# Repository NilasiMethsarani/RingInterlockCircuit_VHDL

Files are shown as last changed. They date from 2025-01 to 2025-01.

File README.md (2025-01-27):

Ring Interlock Circuit for EV Charging

This repository contains the design and implementation of a Ring Interlock Circuit for electric vehicle (EV) charging, using a CPLD (Complex Programmable Logic Device), specifically the EPM240T100C5N. The interlock circuit enhances the safety, efficiency, and reliability of EV charging systems by ensuring dynamic power sharing and robust fault prevention mechanisms.
Key Features

    Dynamic Power Sharing: Efficient distribution of power between multiple EVs to optimize charging performance.
    Enhanced Prioritization: Ensures prioritized power delivery based on load requirements.
    Short Circuit Prevention: Detects and prevents potential short circuits during charging.
    Compact and Scalable Design: Designed for scalability, leveraging the EPM240T100C5N CPLD for cost-effective implementation.

Design Components

    Technology Used:
        CPLD Model: EPM240T100C5N
        Quartus Prime for synthesis and implementation.
        ModelSim for simulation.
        Proteus for circuit-level design and testing.

    Input Signals:
        EV charging status.
        Fault detection inputs.
        Load conditions for power prioritization.

    Output Signals:
        Control signals to charging ports.
        Fault notifications.
        Power allocation indicators.

Objectives

    Ensure safe and efficient charging of multiple EVs using an interlock mechanism.
    Provide a cost-effective solution with minimal hardware overhead.
    Test and validate the design against real-world fault conditions.

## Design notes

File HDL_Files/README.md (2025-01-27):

# Interlock Combined Module

This Verilog module `InterlockCombined` combines multiple instances of `Interlock` modules to create a comprehensive interlocking mechanism for controlling various contacts or devices. 

## Description

The `InterlockCombined` module integrates eight individual `Interlock` modules, each responsible for managing the interlocking logic for a specific set of contacts or devices. These modules are named `InterlockA` through `InterlockH`.

## Inputs

- **i_AA to i_HH**: Feedback inputs representing the current state of each contactor or device.
  
## Outputs

- **o_A to o_H**: Outputs controlling the activation of each contactor or device based on the interlocking logic.

## Interlocking Logic

The interlocking logic for each contactor or device is implemented within their respective `Interlock` modules. These modules utilize the feedback inputs to determine whether a particular contactor or device can be activated based on predefined interlocking conditions.

## Usage

To use the `InterlockCombined` module in your Verilog design, instantiate it in your top-level module and connect the required inputs and outputs as shown in the example provided.

```verilog
module YourTopModule (
    // Define your inputs and outputs here
    ...
);

    // Instantiate InterlockCombined module
    InterlockCombined Interlock (
        .i_AA(input_signal_AA),
        .i_BA(input_signal_BA),
        // Connect other input signals
        .o_A(output_signal_A),
        .o_B(output_signal_B),
        // Connect other output signals
    );

    // Other module instantiations and logic
    ...

endmodule

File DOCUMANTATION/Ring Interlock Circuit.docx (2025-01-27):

Ring Interlock Circuit

Introduction

In the pursuit of safe and efficient electric vehicle (EV) charging infrastructure, the evolution from sequential circuits to ring interlock circuits marks a significant advancement. The transition is driven by the imperative to enhance power sharing capabilities while mitigating potential risks, such as short circuits that could lead to hazardous situations including fires.

Previously, sequential circuits comprised four modules with two ports each, facilitating the connection of vehicles to the charging system. However, inherent limitations in sequential configurations necessitated a paradigm shift towards ring interlock circuits, wherein the safety and efficiency of EV charging systems are significantly augmented.

The fundamental principle guiding the development of ring interlock circuits is twofold: power sharing and prioritization. In essence, the system orchestrates the allocation of power among connected vehicles dynamically, ensuring equitable charging while accommodating varying demands. This innovation enables seamless integration of multiple vehicles into the charging infrastructure, fostering scalability and adaptability to evolving needs.

Central to the design philosophy of ring interlock circuits is the preservation of safety. Unlike sequential circuits, where the risk of short circuits between vehicles posed a formidable challenge, ring interlock configurations mitigate this risk by enforcing a strict prohibition on short paths between vehicles. This crucial safeguard ensures that the charging process proceeds without compromising safety or jeopardizing the integrity of the system.

Moreover, the modular nature of ring interlock circuits empowers operators to customize charging priorities based on user preferences and operational requirements. By allocating higher priority to specific vehicles, such as those in urgent need of charging, while maintaining equitable access for all users, the system optimizes resource utilization and enhances user satisfaction.

Comparison between Previous Sequential Circuit and Ring Interlock Circuit:

Previous Sequential Circuit:

1. Topology: The previous sequential circuit comprised a linear topology, with four modules arranged sequentially. Each module featured two ports for connecting vehicles.

2. Operation: Vehicles were connected to the ports of the modules sequentially, resulting in a linear flow of power through the system. Charging prioritization was limited, typically following a first-come, first-served basis.

3. Constraints: One of the primary constraints of the sequential circuit was the potential for short paths between vehicles, leading to safety hazards such as short circuits and fire risks.

4. Logic Development: The logic governing the operation of the sequential circuit was relatively straightforward, primarily focusing on managing the sequential flow of power to connected vehicles. Safety protocols were limited to basic measures to prevent short circuits.

F

E

D

C

B

A

Here A, B, C, D, E and F represent the feedbacks of modules

(contactors) & A^(-1) , B^(-1) , C^(-1) , D^(-1) , E^(-1) and F^(-1) represent the current input status.

A→(ABCDEFA^(-1) )^(-1)

B→(ABCDEFB^(-1) )^(-1)

C→(ABCDEFC^(-1) )^(-1)

D→(ABCDEFD^(-1) )^(-1)

E→(ABCDEFE^(-1) )^(-1)

F→(ABCDEFF^(-1) )^(-1)

Ring Interlock Circuit:

1. Topology: The ring interlock circuit features a circular or ring-shaped topology, with four modules interconnected in a closed loop. Each module retains four ports for vehicle connection.

2. Operation: In contrast to the linear flow of power in the sequential circuit, the ring interlock circuit enables dynamic power sharing among connected vehicles. Charging prioritization is enhanced, allowing for the allocation of higher priority to specific vehicles based on user requirements.

3. Constraints: The ring interlock circuit addresses the safety concerns of the previous sequential circuit by enforcing strict prohibition on short paths between vehicles. This significantly reduces the risk of short circuits and associated safety hazards.

4. Logic Development: The logic development for the ring interlock circuit is more intricate compared to the previous sequential circuit. It involves algorithms and protocols for dynamic power allocation, prioritization of charging, and stringent safety measures to prevent short paths between vehicles.

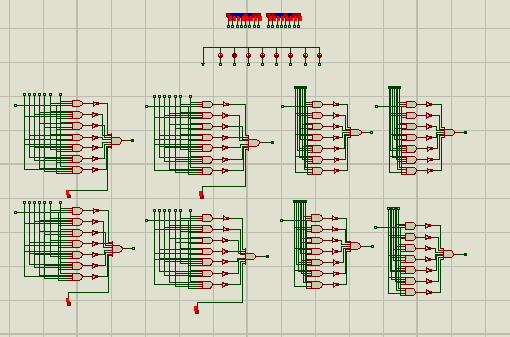
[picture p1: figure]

-Contactors

- Ports

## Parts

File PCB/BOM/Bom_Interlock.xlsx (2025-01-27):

Part | Qty | Manufacturer | Manufacturer Part Number | DigiKey Part Number | LCSC Part Number | Description | Link
J1, J2 | 2 | TE Connectivity AMP Connectors | 1-2314812-6 | 17-1-2314812-6-ND |  | 16P,2MM,B-B,REC,DRVT,2.0,0.1AU,T | Link (https://www.digikey.com/en/products/detail/te-connectivity-amp-connectors/1-2314812-6/11502796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)
J3 | 1 | Würth Elektronik | 61301021821 | 732-2861-ND |  | CONN HDR 10POS 0.1 GOLD PCB | Link (https://www.digikey.com/en/products/detail/w%C3%BCrth-elektronik/61301021821/2508630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)
R1, R2, R3, R4, R5, R6, R7, R8, R14 | 9 | Stackpole Electronics Inc | RMCF0603JT220R | RMCF0603JT220RTR-ND |  | RES 220 OHM 5% 1/10W 0603 | Link (https://www.digikey.com/en/products/detail/stackpole-electronics-inc/RMCF0603JT220R/1758014)
R9, R10, R11, R12, R13 | 5 | Bourns Inc. | CRT0603-BY-1002EAS | CRT0603-BY-1002EASTR-ND |  | RES SMD 10K OHM 1/10W 0.1% 0603 | Link (https://www.digikey.com/en/products/detail/bourns-inc/CRT0603-BY-1002EAS/5992173)
C1, C2, C3, C4, C5, C6, C7, C8, C9 | 9 | Murata Electronics | GRM188R71C104MA01D | 490-11510-2-ND |  | CAP CER 0.1UF 16V X7R 0603 | Link (https://www.digikey.com/en/products/detail/murata-electronics/GRM188R71C104MA01D/4420803)
C10 | 1 | Murata Electronics | GRM188R61C106MAALD | 490-10729-2-ND |  | CAP CER 10UF 16V X5R 0603 | Link (https://www.digikey.com/en/products/detail/murata-electronics/GRM188R61C106MAALD/5251371)
C11 | 1 | KEMET | C0603C104K4RAC3077 | 399-C0603C104K4RAC3077TR-ND |  | .100UF 16.0V | Link (https://www.digikey.com/en/products/detail/kemet/C0603C104K4RAC3077/22058627)
D1, D2, D3, D4, D5, D6, D7, D8, D9 | 9 | Broadcom Limited | HSMS-C190 | 516-1422-2-ND |  | LED RED DIFFUSED SMD | Link (https://www.digikey.com/en/products/detail/broadcom-limited/HSMS-C190/637683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)
Y1 | 1 | CTS-Frequency Controls | CB3LV-3C-50M000000 | 110-CB3LV-3C-50M000000TR-ND |  | XTAL OSC XO 50.0000MHZ HCMOS TTL | Link (https://www.digikey.com/en/products/detail/cts-frequency-controls/CB3LV-3C-50M000000/280321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)
U1 | 1 | Intel | EPM240T100C5N | 544-1964-ND | C10041 | IC CPLD 192MC 4.7NS 100TQFP | Link (https://www.lcsc.com/product-detail/Programmable-Logic-Device-CPLDs-FPGAs_Intel-Altera-EPM240T100C5N_C10041.html)
U2 | 1 | Texas Instruments | TLV1117-33IDCYRG3 | 296-50543-2-ND |  | IC REG LIN 3.3V 800MA SOT223-4 | Link (https://www.digikey.com/en/products/detail/texas-instruments/TLV1117-33IDCYRG3/1677132)

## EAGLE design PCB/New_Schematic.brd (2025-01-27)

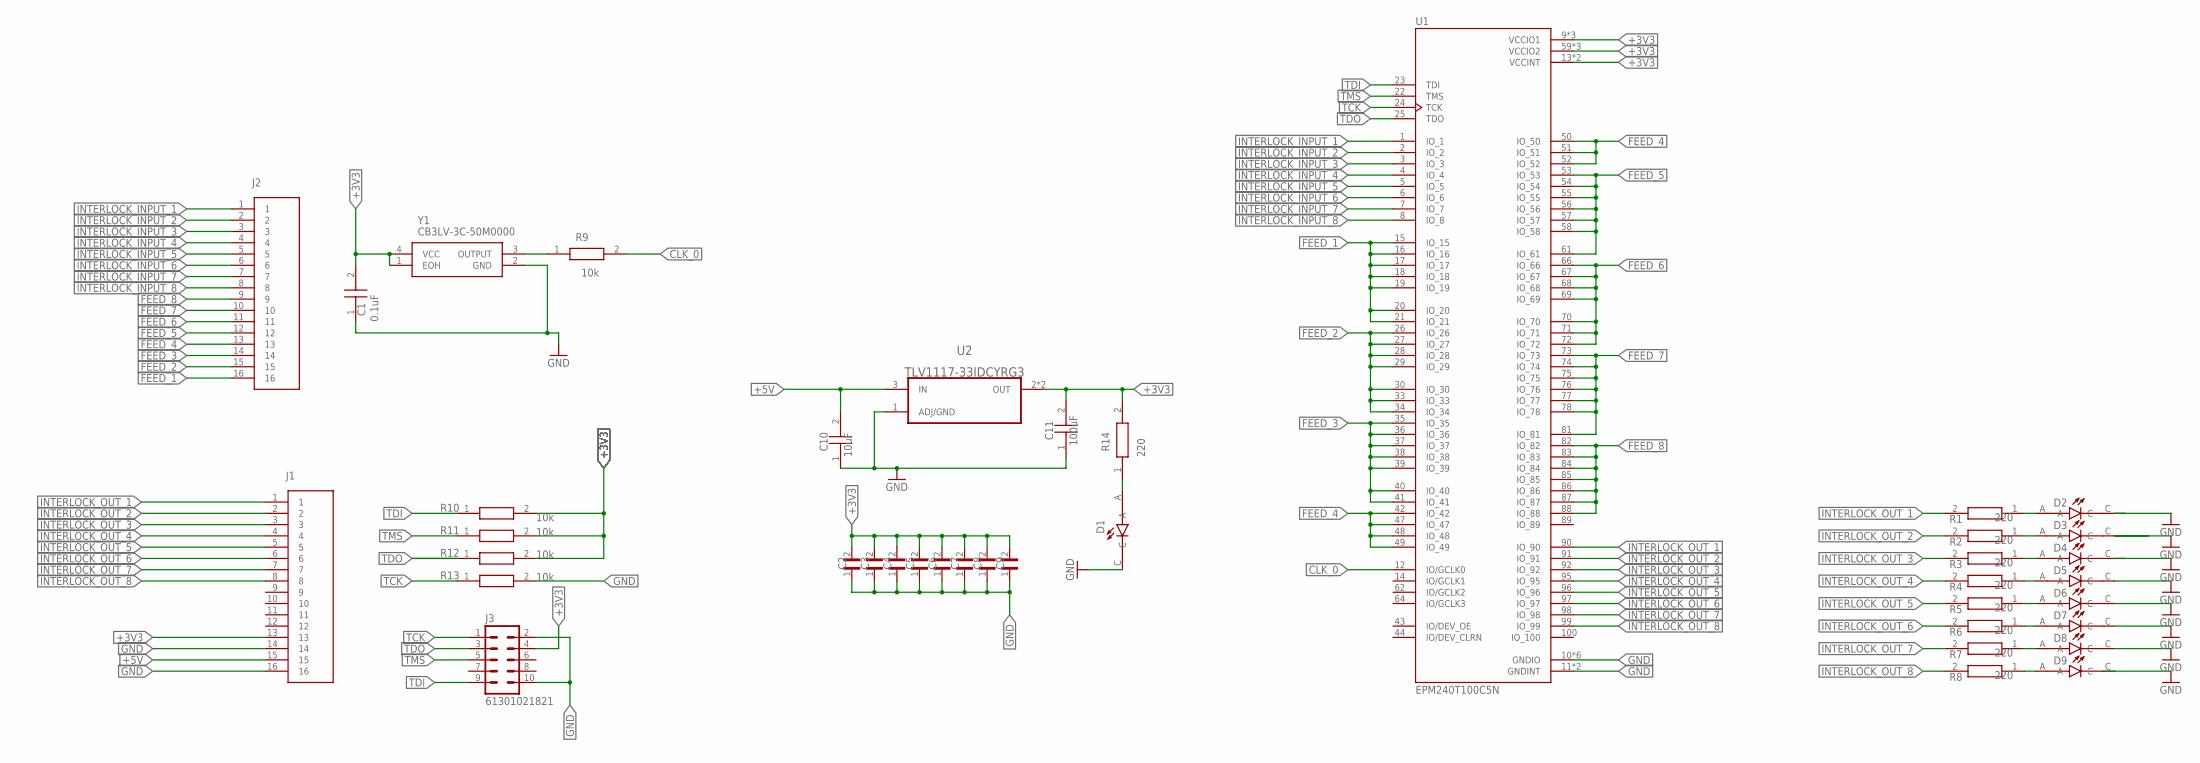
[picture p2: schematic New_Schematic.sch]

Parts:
C1: GRM188R71C104MA01D; CAPC1608X90N
C2, C3, C4, C5, C6, C7, C8, C9: GRM155R70J104KA01D; CAPC1005X55N
C10, C11: 0603X106M160CT; CAPC1608X95N
D1, D2, D3, D4, D5, D6, D7, D8, D9: HSMS-C190; LEDM1608X80
J1, J2: 1-2314812-6; TE_1-2314812-6
J3: 61301021821; 2X05-PIN
R1, R2, R3, R4, R5, R6, R7, R8, R14: MCT06030D2200BP100; RESC1608X55N
R9, R10, R11, R12, R13: CRT0603-BY-1002EAS; RESC1608X60N
U1: EPM240T100C5N; QFP50P1600X1600X120-100N
U2: TLV1117-33IDCYRG3; SOT230P700X180-4N
Y1: CB3LV-3C-50M0000; CB3LV3C50M0000

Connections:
+3V3: C1.2, C2.2, C3.2, C4.2, C5.2, C6.2, C7.2, C8.2, C9.2, C11.2, J1.13, J3.4, R10.2, R11.2, R12.2, R14.2, U1.9 (VCCIO1), U1.13 (VCCINT), U1.31 (VCCIO1), U1.45 (VCCIO1), U1.59 (VCCIO2), U1.63 (VCCINT), U1.80 (VCCIO2), U1.94 (VCCIO2), U2.2 (OUT), U2.4 (OUT), Y1.1 (EOH), Y1.4 (VCC)
+5V: C10.2, J1.15, U2.3 (IN)
CLK_0: R9.2, U1.12 (IO/GCLK0)
FEED_1: J2.16, U1.15 (IO_15), U1.16 (IO_16), U1.17 (IO_17), U1.18 (IO_18), U1.19 (IO_19), U1.20 (IO_20), U1.21 (IO_21)
FEED_2: J2.15, U1.26 (IO_26), U1.27 (IO_27), U1.28 (IO_28), U1.29 (IO_29), U1.30 (IO_30), U1.33 (IO_33), U1.34 (IO_34)
FEED_3: J2.14, U1.35 (IO_35), U1.36 (IO_36), U1.37 (IO_37), U1.38 (IO_38), U1.39 (IO_39), U1.40 (IO_40), U1.41 (IO_41)
FEED_4: J2.13, U1.42 (IO_42), U1.47 (IO_47), U1.48 (IO_48), U1.49 (IO_49), U1.50 (IO_50), U1.51 (IO_51), U1.52 (IO_52)
FEED_5: J2.12, U1.53 (IO_53), U1.54 (IO_54), U1.55 (IO_55), U1.56 (IO_56), U1.57 (IO_57), U1.58 (IO_58), U1.61 (IO_61)
FEED_6: J2.11, U1.66 (IO_66), U1.67 (IO_67), U1.68 (IO_68), U1.69 (IO_69), U1.70 (IO_70), U1.71 (IO_71), U1.72 (IO_72)
FEED_7: J2.10, U1.73 (IO_73), U1.74 (IO_74), U1.75 (IO_75), U1.76 (IO_76), U1.77 (IO_77), U1.78 (IO_78), U1.81 (IO_81)
FEED_8: J2.9, U1.82 (IO_82), U1.83 (IO_83), U1.84 (IO_84), U1.85 (IO_85), U1.86 (IO_86), U1.87 (IO_87), U1.88 (IO_88)
GND: C1.1, C2.1, C3.1, C4.1, C5.1, C6.1, C7.1, C8.1, C9.1, C10.1, C11.1, D1.C, D2.C, D3.C, D4.C, D5.C, D6.C, D7.C, D8.C, D9.C, J1.14, J1.16, J3.2, J3.10, R13.2, U1.10 (GNDIO), U1.11 (GNDINT), U1.32 (GNDIO), U1.46 (GNDIO), U1.60 (GNDIO), U1.65 (GNDINT), U1.79 (GNDIO), U1.93 (GNDIO), U2.1 (ADJ/GND), Y1.2 (GND)
INTERLOCK_INPUT_1: J2.1, U1.1 (IO_1)
INTERLOCK_INPUT_2: J2.2, U1.2 (IO_2)
INTERLOCK_INPUT_3: J2.3, U1.3 (IO_3)
INTERLOCK_INPUT_4: J2.4, U1.4 (IO_4)
INTERLOCK_INPUT_5: J2.5, U1.5 (IO_5)
INTERLOCK_INPUT_6: J2.6, U1.6 (IO_6)
INTERLOCK_INPUT_7: J2.7, U1.7 (IO_7)
INTERLOCK_INPUT_8: J2.8, U1.8 (IO_8)
INTERLOCK_OUT_1: J1.1, R1.2, U1.90 (IO_90)
INTERLOCK_OUT_2: J1.2, R2.2, U1.91 (IO_91)
INTERLOCK_OUT_3: J1.3, R3.2, U1.92 (IO_92)
INTERLOCK_OUT_4: J1.4, R4.2, U1.95 (IO_95)
INTERLOCK_OUT_5: J1.5, R5.2, U1.96 (IO_96)
INTERLOCK_OUT_6: J1.6, R6.2, U1.97 (IO_97)
INTERLOCK_OUT_7: J1.7, R7.2, U1.98 (IO_98)
INTERLOCK_OUT_8: J1.8, R8.2, U1.99 (IO_99)
unnamed: D2.A, R1.1
unnamed: D3.A, R2.1
unnamed: D4.A, R3.1
unnamed: D5.A, R4.1
unnamed: D6.A, R5.1
unnamed: D7.A, R6.1
unnamed: D8.A, R7.1
unnamed: D9.A, R8.1
unnamed: R9.1, Y1.3 (OUTPUT)
unnamed: D1.A, R14.1
TCK: J3.1, R13.1, U1.24 (TCK)
TDI: J3.9, R10.1, U1.23 (TDI)
TDO: J3.3, R12.1, U1.25 (TDO)
TMS: J3.5, R11.1, U1.22 (TMS)

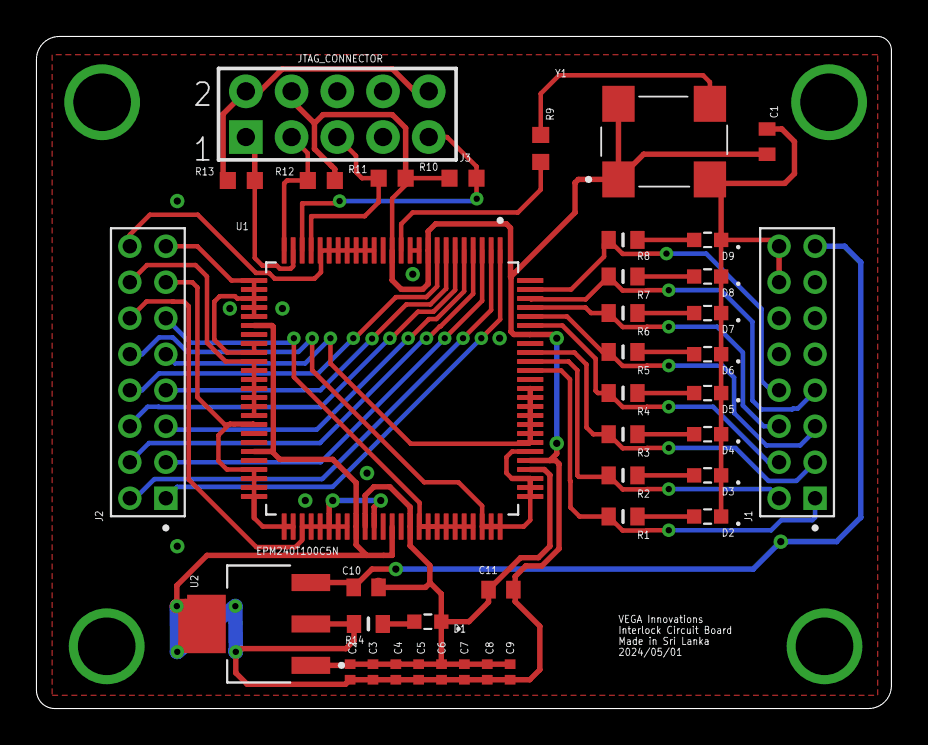
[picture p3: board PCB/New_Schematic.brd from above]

Board: 2 copper layers, 47.5 x 37.3 mm, 40 parts (0 on the bottom side), 42 nets.

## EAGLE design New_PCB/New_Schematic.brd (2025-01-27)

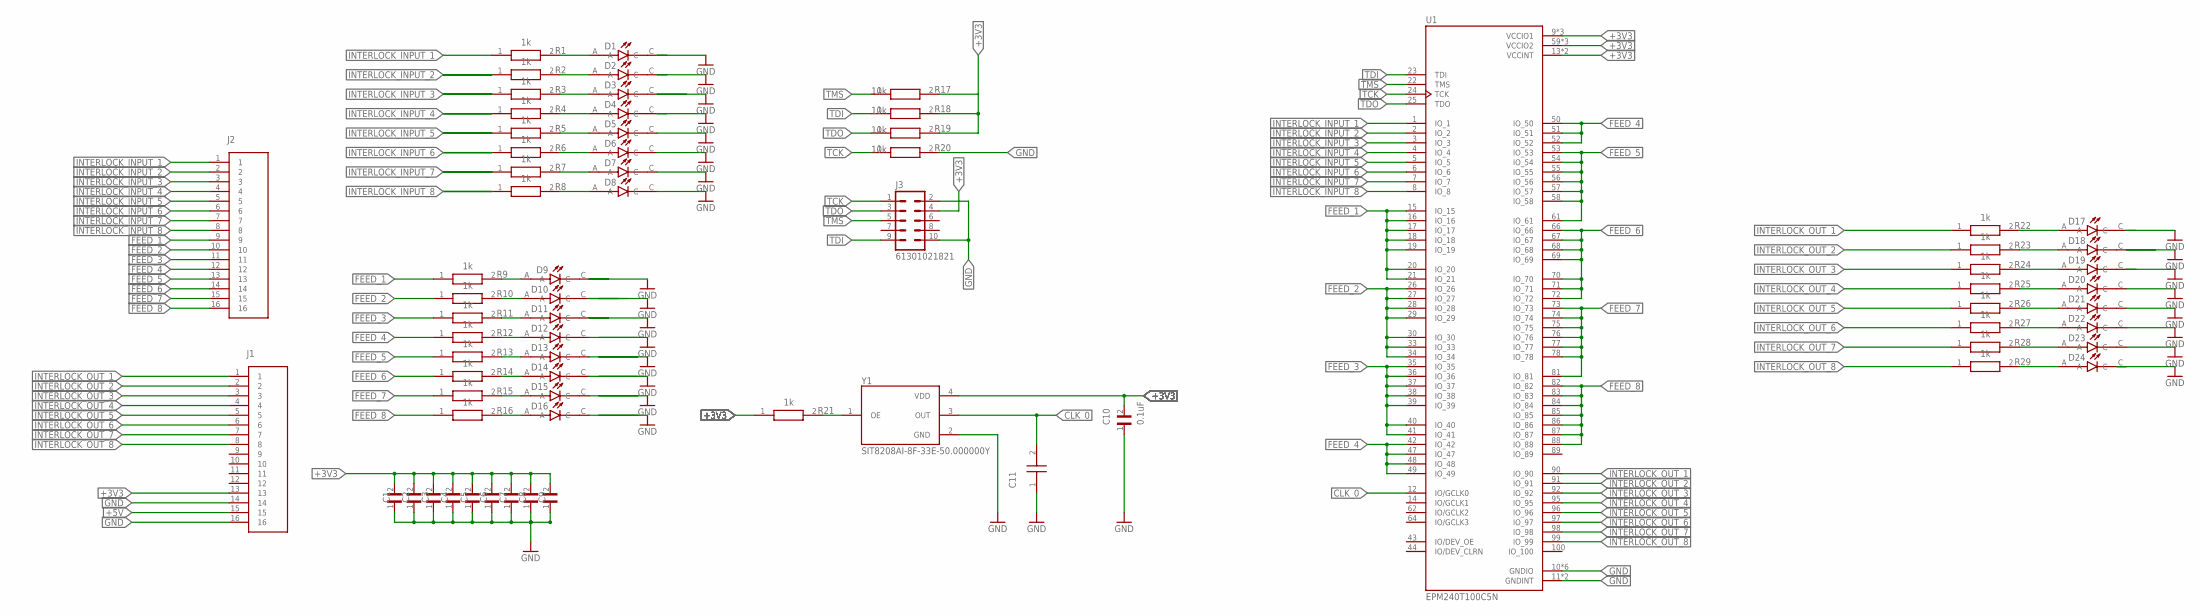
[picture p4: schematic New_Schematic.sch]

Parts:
C1, C2, C3, C4, C5, C6, C7, C8, C9, C10: GRM155R70J104KA01D; CAPC1005X55N
C11: GRM1883U2A150JZ01B; CAPC1608X90N
D1, D2, D3, D4, D5, D6, D7, D8, D9, D10, D11, D12, D13, D14, D15, D16, D17, D18, D19, D20, D21, D22, D23, D24: HSMS-C190; LEDM1608X80
J1, J2: 1-2314812-6; TE_1-2314812-6
J3: 61301021821; 2X05-PIN
R1, R2, R3, R4, R5, R6, R7, R8, R9, R10, R11, R12, R13, R14, R15, R16, R21, R22, R23, R24, R25, R26, R27, R28, R29: ERJS03D1001V; RESC1608X55N
R17, R18, R19, R20: CRT0603-BY-1002EAS; RESC1608X60N
U1: EPM240T100C5N; QFP50P1600X1600X120-100N
Y1: SIT8208AI-8F-33E-50.000000Y; OSC_SIT8208AI-8F-33E-50.000000Y

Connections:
+3V3: C1.2, C2.2, C3.2, C4.2, C5.2, C6.2, C7.2, C8.2, C9.2, C10.2, J1.13, J3.4, R17.2, R18.2, R19.2, R21.1, U1.9 (VCCIO1), U1.13 (VCCINT), U1.31 (VCCIO1), U1.45 (VCCIO1), U1.59 (VCCIO2), U1.63 (VCCINT), U1.80 (VCCIO2), U1.94 (VCCIO2), Y1.4 (VDD)
+5V: J1.15
CLK_0: C11.2, U1.12 (IO/GCLK0), Y1.3 (OUT)
FEED_1: J2.9, R9.1, U1.15 (IO_15), U1.16 (IO_16), U1.17 (IO_17), U1.18 (IO_18), U1.19 (IO_19), U1.20 (IO_20), U1.21 (IO_21)
FEED_2: J2.10, R10.1, U1.26 (IO_26), U1.27 (IO_27), U1.28 (IO_28), U1.29 (IO_29), U1.30 (IO_30), U1.33 (IO_33), U1.34 (IO_34)
FEED_3: J2.11, R11.1, U1.35 (IO_35), U1.36 (IO_36), U1.37 (IO_37), U1.38 (IO_38), U1.39 (IO_39), U1.40 (IO_40), U1.41 (IO_41)
FEED_4: J2.12, R12.1, U1.42 (IO_42), U1.47 (IO_47), U1.48 (IO_48), U1.49 (IO_49), U1.50 (IO_50), U1.51 (IO_51), U1.52 (IO_52)
FEED_5: J2.13, R13.1, U1.53 (IO_53), U1.54 (IO_54), U1.55 (IO_55), U1.56 (IO_56), U1.57 (IO_57), U1.58 (IO_58), U1.61 (IO_61)
FEED_6: J2.14, R14.1, U1.66 (IO_66), U1.67 (IO_67), U1.68 (IO_68), U1.69 (IO_69), U1.70 (IO_70), U1.71 (IO_71), U1.72 (IO_72)
FEED_7: J2.15, R15.1, U1.73 (IO_73), U1.74 (IO_74), U1.75 (IO_75), U1.76 (IO_76), U1.77 (IO_77), U1.78 (IO_78), U1.81 (IO_81)
FEED_8: J2.16, R16.1, U1.82 (IO_82), U1.83 (IO_83), U1.84 (IO_84), U1.85 (IO_85), U1.86 (IO_86), U1.87 (IO_87), U1.88 (IO_88)
GND: C1.1, C2.1, C3.1, C4.1, C5.1, C6.1, C7.1, C8.1, C9.1, C10.1, C11.1, D1.C, D2.C, D3.C, D4.C, D5.C, D6.C, D7.C, D8.C, D9.C, D10.C, D11.C, D12.C, D13.C, D14.C, D15.C, D16.C, D17.C, D18.C, D19.C, D20.C, D21.C, D22.C, D23.C, D24.C, J1.14, J1.16, J3.2, J3.10, R20.2, U1.10 (GNDIO), U1.11 (GNDINT), U1.32 (GNDIO), U1.46 (GNDIO), U1.60 (GNDIO), U1.65 (GNDINT), U1.79 (GNDIO), U1.93 (GNDIO), Y1.2 (GND)
INTERLOCK_INPUT_1: J2.1, R1.1, U1.1 (IO_1)
INTERLOCK_INPUT_2: J2.2, R2.1, U1.2 (IO_2)
INTERLOCK_INPUT_3: J2.3, R3.1, U1.3 (IO_3)
INTERLOCK_INPUT_4: J2.4, R4.1, U1.4 (IO_4)
INTERLOCK_INPUT_5: J2.5, R5.1, U1.5 (IO_5)
INTERLOCK_INPUT_6: J2.6, R6.1, U1.6 (IO_6)
INTERLOCK_INPUT_7: J2.7, R7.1, U1.7 (IO_7)
INTERLOCK_INPUT_8: J2.8, R8.1, U1.8 (IO_8)
INTERLOCK_OUT_1: J1.1, R22.1, U1.90 (IO_90)
INTERLOCK_OUT_2: J1.2, R23.1, U1.91 (IO_91)
INTERLOCK_OUT_3: J1.3, R24.1, U1.92 (IO_92)
INTERLOCK_OUT_4: J1.4, R25.1, U1.95 (IO_95)
INTERLOCK_OUT_5: J1.5, R26.1, U1.96 (IO_96)
INTERLOCK_OUT_6: J1.6, R27.1, U1.97 (IO_97)
INTERLOCK_OUT_7: J1.7, R28.1, U1.98 (IO_98)
INTERLOCK_OUT_8: J1.8, R29.1, U1.99 (IO_99)
unnamed: D2.A, R2.2
unnamed: D3.A, R3.2
unnamed: D4.A, R4.2
unnamed: D5.A, R5.2
unnamed: D6.A, R6.2
unnamed: D7.A, R7.2
unnamed: D8.A, R8.2
unnamed: D16.A, R16.2
unnamed: D1.A, R1.2
unnamed: R21.2, Y1.1 (OE)
unnamed: D9.A, R9.2
unnamed: D17.A, R22.2
unnamed: D18.A, R23.2
unnamed: D10.A, R10.2
unnamed: D11.A, R11.2
unnamed: D12.A, R12.2
unnamed: D13.A, R13.2
unnamed: D14.A, R14.2
unnamed: D15.A, R15.2
unnamed: D19.A, R24.2
unnamed: D20.A, R25.2
unnamed: D21.A, R26.2
unnamed: D22.A, R27.2
unnamed: D23.A, R28.2
unnamed: D24.A, R29.2
TCK: J3.1, R20.1, U1.24 (TCK)
TDI: J3.9, R18.1, U1.23 (TDI)
TDO: J3.3, R19.1, U1.25 (TDO)
TMS: J3.5, R17.1, U1.22 (TMS)

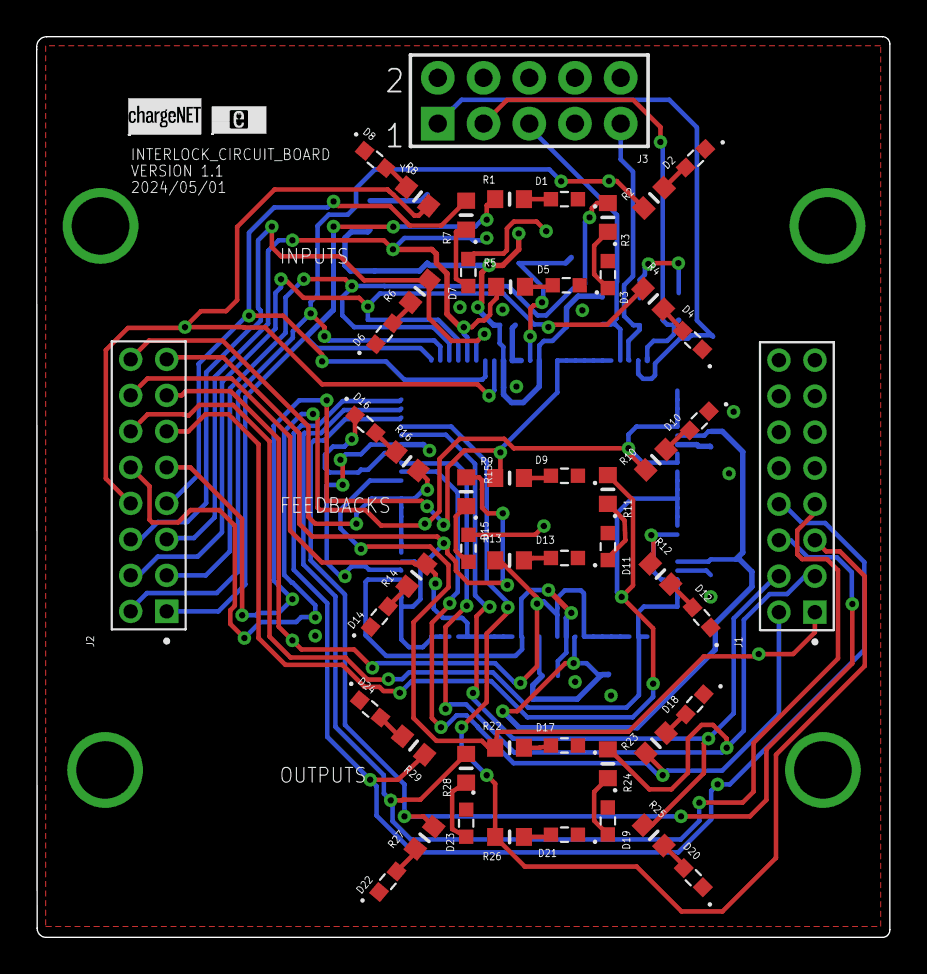
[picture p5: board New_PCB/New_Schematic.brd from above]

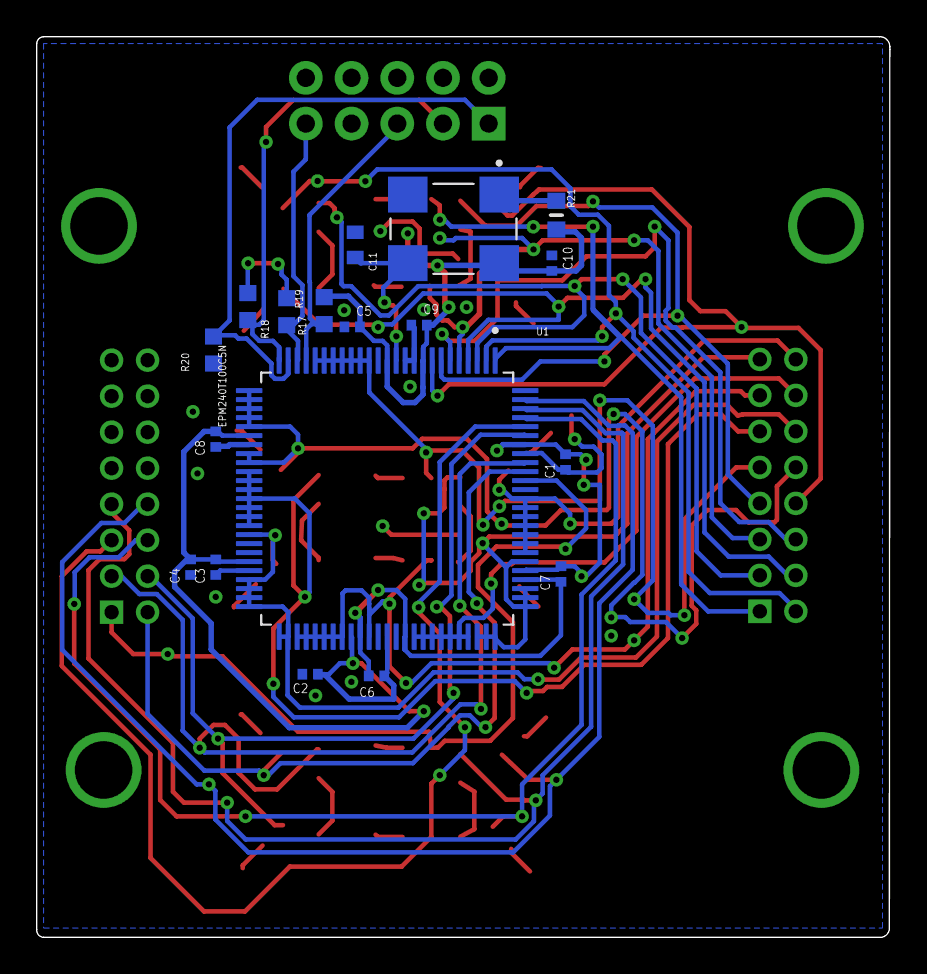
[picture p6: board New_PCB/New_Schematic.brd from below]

Board: 4 copper layers, 47.4 x 50.0 mm, 69 parts (18 on the bottom side), 56 nets.

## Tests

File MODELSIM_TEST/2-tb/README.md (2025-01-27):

# Useful ModelSim/VSIM commands
## Simulate for the first time
Note: WLF stands for wave log format
```
vsim -wlf Ilock.wlf work.Ilock_tb
run -all
quit -sim
```

## View the waveform without re-simulation
```
vsim -view Ilock.wlf -do Ilock.do
dataset close Ilock
```

## Re-simulation using the same waveform configuration
```
vsim -wlf Ilock.wlf -do Ilock.do -do "run -all" work.Ilock_tb
```
